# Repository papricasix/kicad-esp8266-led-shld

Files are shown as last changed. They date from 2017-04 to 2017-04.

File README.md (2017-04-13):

# kicad-esp8266-led-shld
Schema and PCB design for a ESP8266 "shield"

## PCB shot (not assembled):
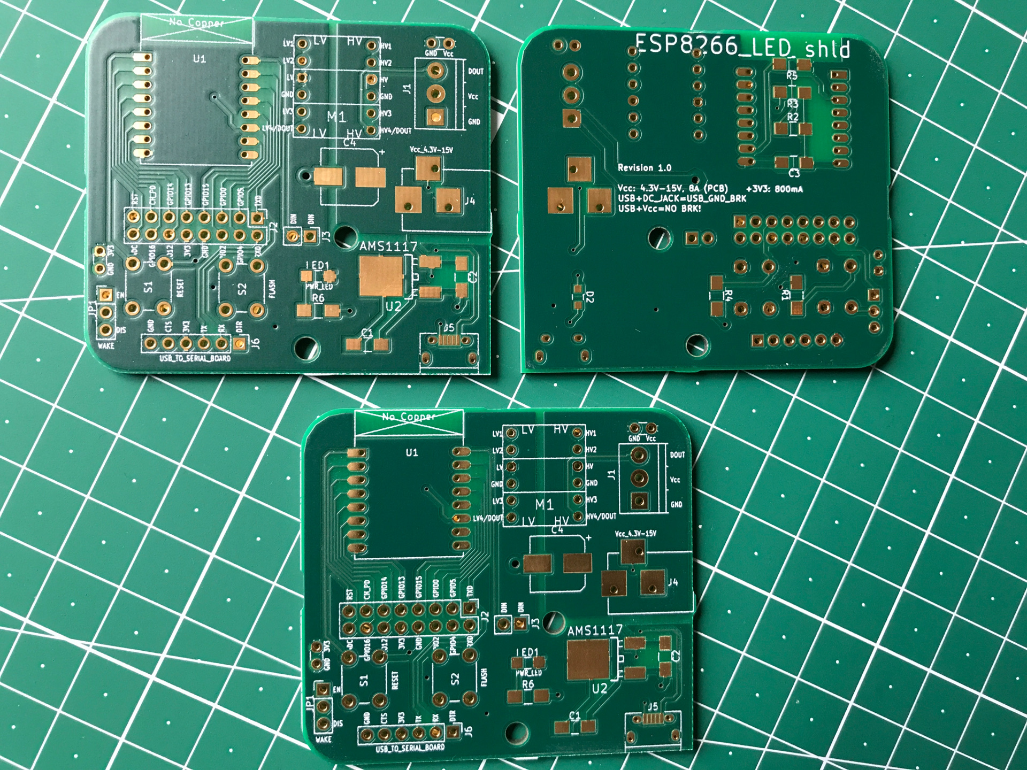
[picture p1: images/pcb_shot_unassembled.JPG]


## PCB layout:
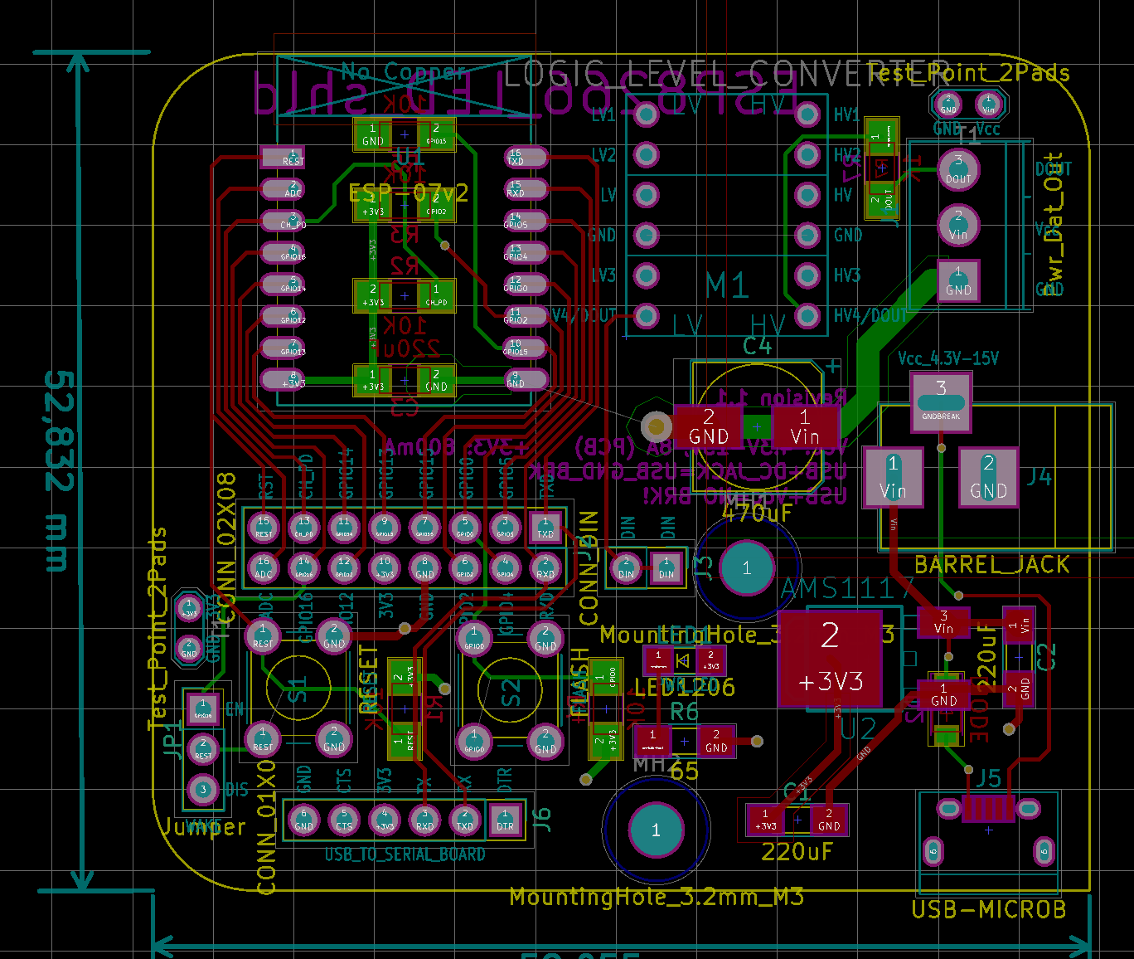
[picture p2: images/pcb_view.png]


## PCB 3D preview (front & back):
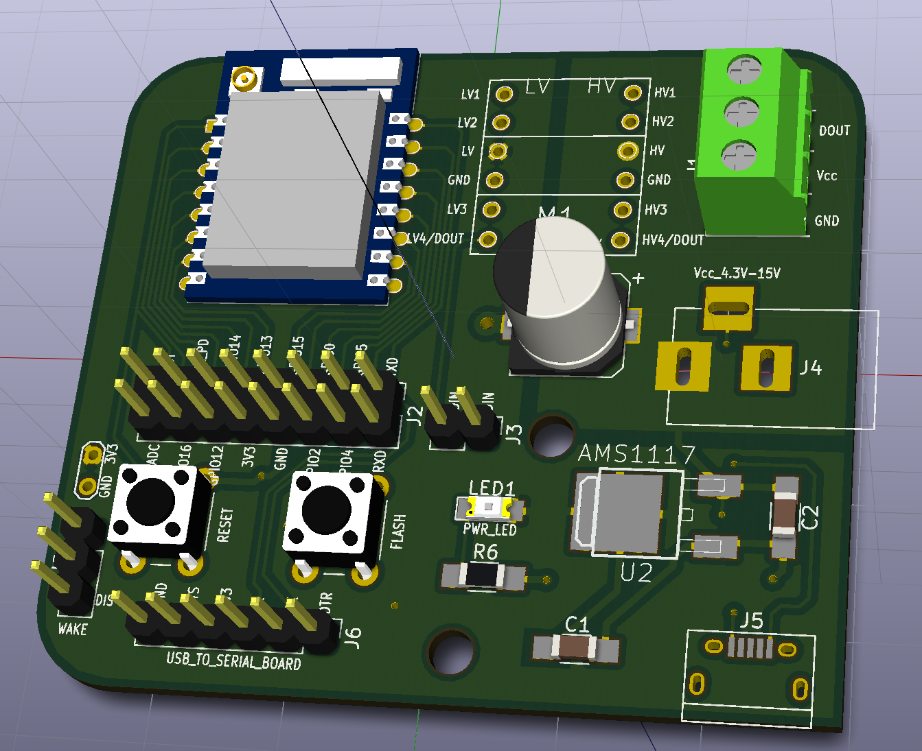
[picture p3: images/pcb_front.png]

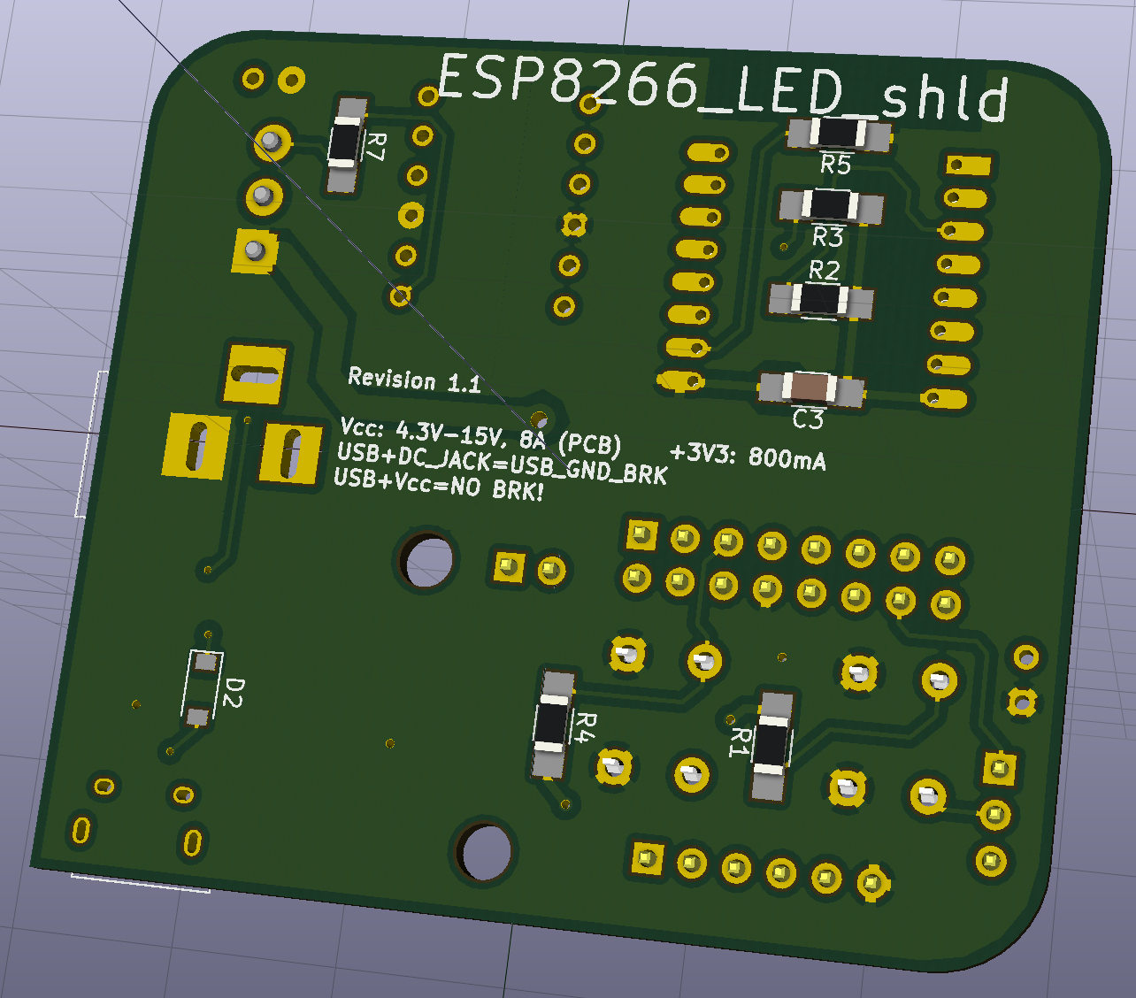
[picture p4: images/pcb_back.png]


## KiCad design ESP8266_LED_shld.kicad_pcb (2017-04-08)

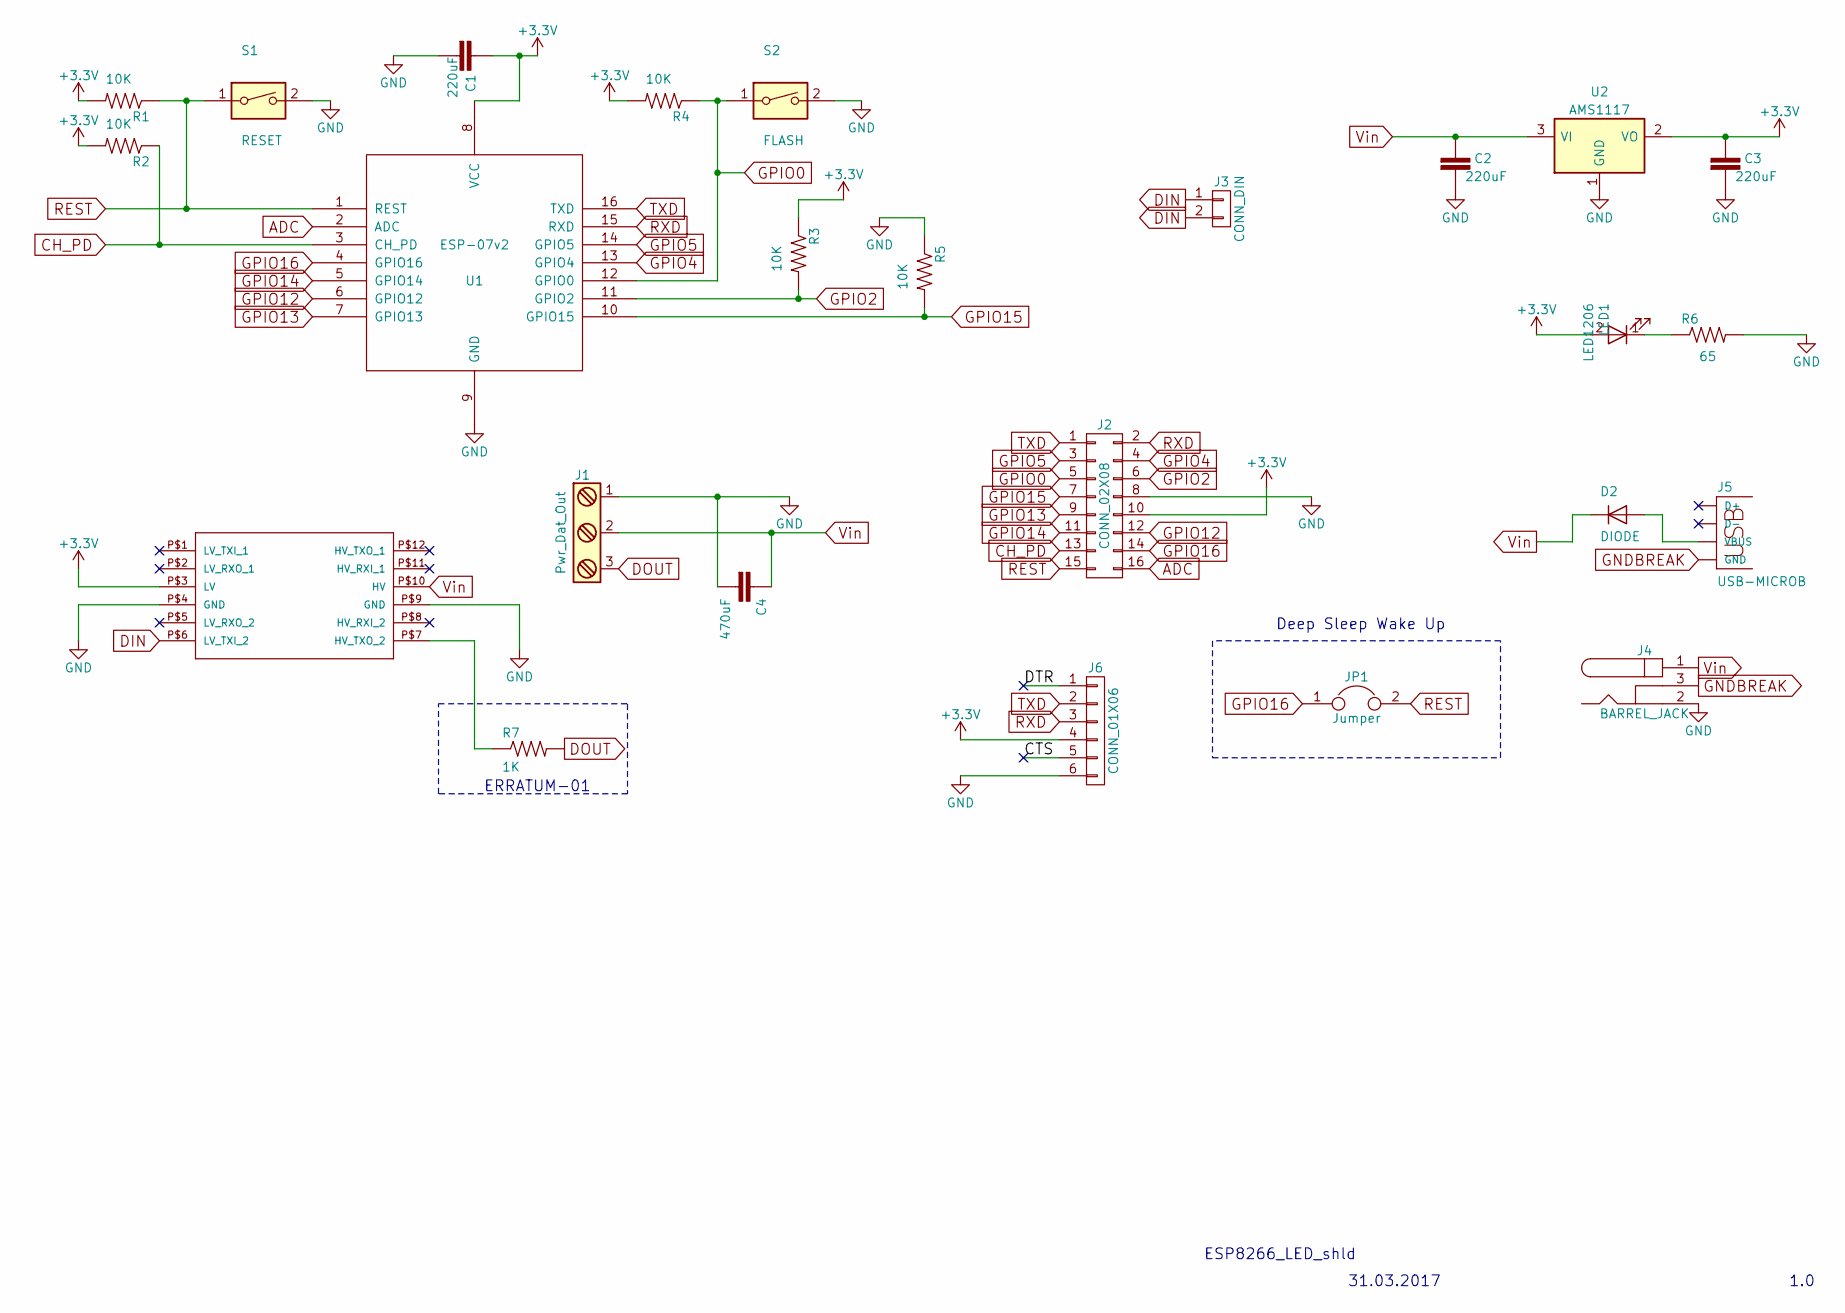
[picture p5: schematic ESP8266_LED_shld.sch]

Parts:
C1, C2, C3: 220uF; 1206
C4: 470uF; CP_Elec_8x10
D2: DIODE; D_SOD-323_HandSoldering
J1: Pwr_Dat_Out; TerminalBlock_Pheonix_PT-3.5mm_3pol
J2: CONN_02X08; Pin_Header_Straight_2x08_Pitch2.54mm
J3: CONN_DIN; Pin_Header_Straight_1x02_Pitch2.54mm
J4: BARREL_JACK
J5: USB-MICROB; USB_Micro-B-revision2
J6: CONN_01X06; Pin_Header_Straight_1x06_Pitch2.54mm
JP1: Jumper; Pin_Header_Straight_1x03_Pitch2.54mm
LED1: LED1206; LED_1206
M1: LOGIC_LEVEL_CONVERTER
R1, R2, R3, R4, R5: 10K; R_1206_HandSoldering
R6: 65; R_1206_HandSoldering
R7: 1K; R_1206_HandSoldering
S1: RESET; SW_PUSH_6mm
S2: FLASH; SW_PUSH_6mm
U1: ESP-07v2
U2: AMS1117; V-REG_DPACK-revision2

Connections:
+3V3: C1.1, C3.1, J2.10, J6.4, LED1.2 (A), M1.P$3 (LV), R1.2, R2.2, R3.1, R4.2, U1.8 (VCC), U2.2 (VO); also elsewhere on the board
/CTS: J6.5
/DTR: J6.1
ADC: J2.16, U1.2 (ADC)
CH_PD: J2.13, R2.1, U1.3 (CH_PD)
DIN: J3.1, J3.2, M1.P$6 (LV_TXI_2)
DOUT: J1.3, R7.2
GND: C1.2, C2.2, C3.2, C4.2, J1.1, J2.8, J4.2, J6.6, M1.P$4 (GND), M1.P$9 (GND), R5.1, R6.2, S1.2, S2.2, U1.9 (GND), U2.1 (GND); also elsewhere on the board
GNDBREAK: J4.3, J5.GND, J5.MT1 (GND), J5.MT2 (GND)
GPIO0: J2.5, R4.1, S2.1, U1.12 (GPIO0)
GPIO2: J2.6, R3.2, U1.11 (GPIO2)
GPIO4: J2.4, U1.13 (GPIO4)
GPIO5: J2.3, U1.14 (GPIO5)
GPIO12: J2.12, U1.6 (GPIO12)
GPIO13: J2.9, U1.7 (GPIO13)
GPIO14: J2.11, U1.5 (GPIO14)
GPIO15: J2.7, R5.2, U1.10 (GPIO15)
GPIO16: J2.14, JP1.1, U1.4 (GPIO16)
unnamed: D2.2 (A), J5.VBUS
unnamed: LED1.1 (K), R6.1
unnamed: M1.P$7 (HV_TXO_2), R7.1
REST: J2.15, JP1.2, R1.1, S1.1, U1.1 (REST)
RXD: J2.2, J6.3, U1.15 (RXD)
TXD: J2.1, J6.2, U1.16 (TXD)
Vin: C2.1, C4.1, D2.1 (K), J1.2, J4.1, M1.P$10 (HV), U2.3 (VI); also elsewhere on the board

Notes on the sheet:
1.0
31.03.2017
ESP8266_LED_shld
Deep Sleep Wake Up
ERRATUM-01

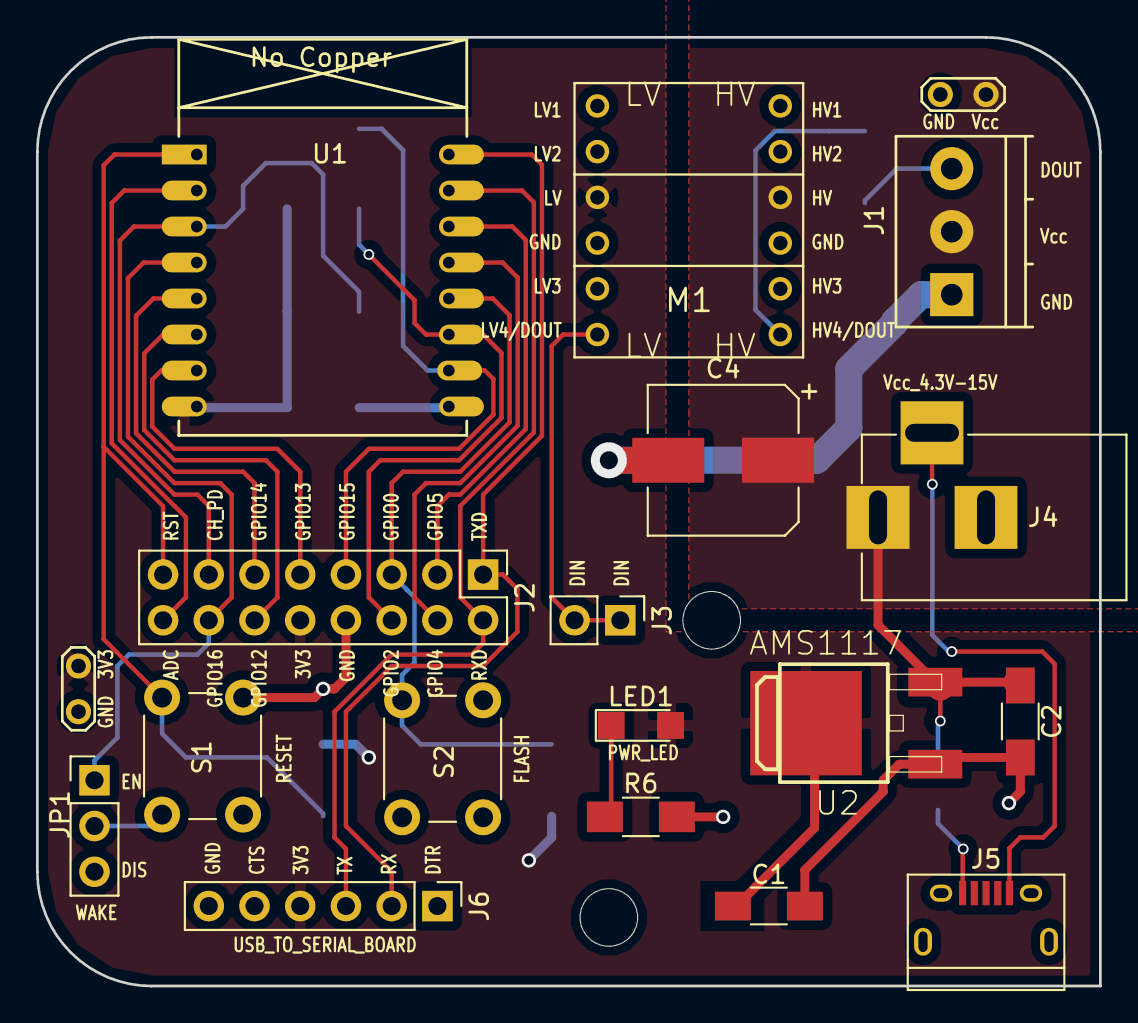
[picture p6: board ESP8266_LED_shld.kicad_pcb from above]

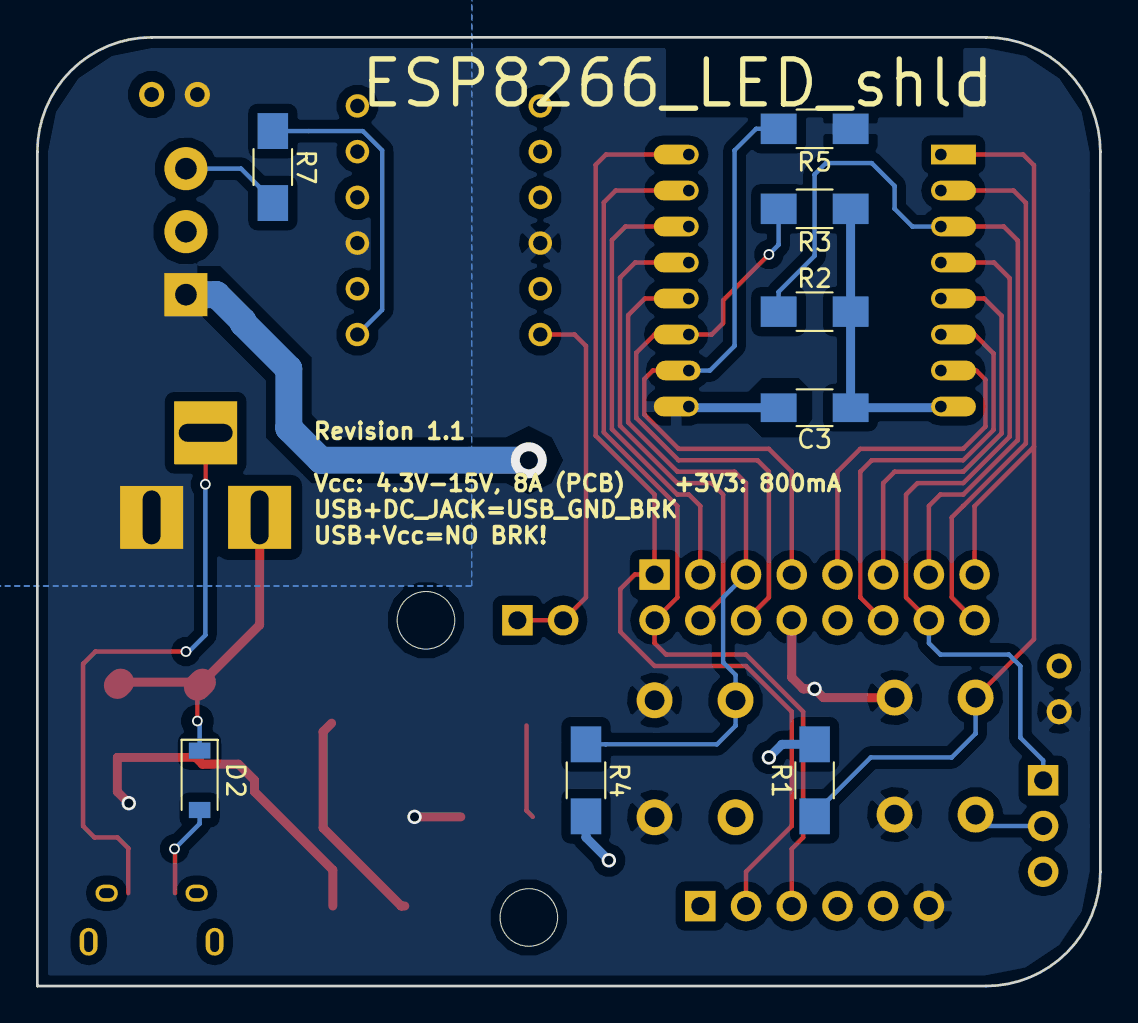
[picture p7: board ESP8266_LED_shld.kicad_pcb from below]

Board: 2 copper layers, 59.1 x 52.7 mm, 29 parts (8 on the bottom side), 23 nets.

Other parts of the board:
MH1, MH2: MountingHole_3.2mm_M3
T1, T1#2: Test_Point_2Pads

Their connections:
+3V3: T1#2.1; also elsewhere on the board
GND: T1.2, T1#2.2; also elsewhere on the board
Vin: T1.1; also elsewhere on the board

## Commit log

2017-04-05 initial version 1.0 (sent to fab)
    [ESP8266_LED_shld.kicad_pcb, ESP8266_LED_shld.sch]
2017-04-05 added resistor between DOUT and HV4 to protect data pin of LED stip and fixed some silk screen labels (positions)
    [ESP8266_LED_shld.kicad_pcb, ESP8266_LED_shld.sch]
2017-04-08 updated PCB design
    [ESP8266_LED_shld.kicad_pcb]
2017-04-13 added pcb shot
